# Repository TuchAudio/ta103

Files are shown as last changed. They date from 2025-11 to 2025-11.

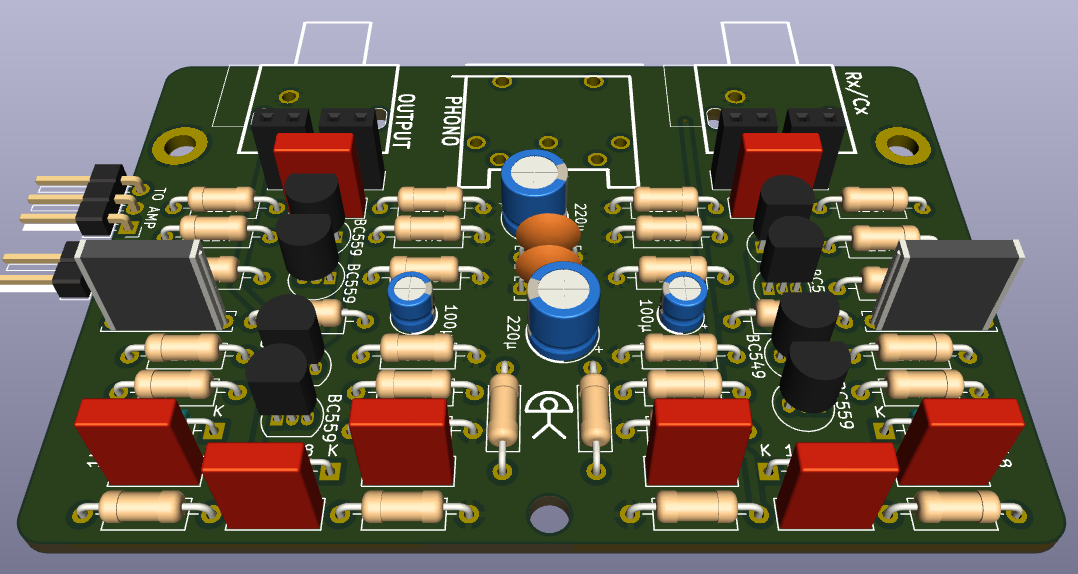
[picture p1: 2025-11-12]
pics/103-render.png

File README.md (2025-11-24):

# TuchAudio 103
Discrete, simple op-amp phono preamp

## Purpose
The most simple discrete op-amp, with **just 4 transistors** per channel -- a _3-transistor_ design was tried, but performed poorly.

## Design quirks

An op-amp this simple doesn't have too much of _open-loop gain_, thus the approximate formulae usually used are **no longer valid**. For this reason, _bass performance_ is just acceptable (but within _DIN 45.500_ specs).

DIN and RCA jacks are provided for signal input. Since the _native_ input impedance is around **110 kΩ**, space for suitable load (`Rx` and `Cx`) is provided for perfect adaptation; but for added flexibility, it is possible to use the free input for a suitable RC combo in parallel, to match the appropriate cartridge load.

Originally intended to be connected thru the [501 Input Selector board](../../../ta501), both output pins and power input are at compatible locations within each board. An aditional RCA **output** jack can be installed in order to use the circuit as a _stand-alone preamp_.

The use of an _asymmetric_ power supply (and its associated feedback _DC-blocking capacitor_) means that **it takes a few seconds** for the preamp to operate after powerup (or a noticeable supply voltage change).

### Stability

As any other amplifier with _asymmetrical power supply_, the PSRR is very poor, thus a **well filtered, stable** power supply is essential. Increasing (within reason) `R115/R215` may help a bit.

### Suggested mods

#### Standalone mode

Despite being designed around a 12 Volt power supply, this can be run from a single **9 Volt battery**, with minor changes and similar performance.

- `R115/R215`: use **220 Ω** instead of 330.
- `R103/R110/R203/R210`: use **8.2 kΩ** instead of 12K.

#### IEC1976/Neumann ammendments

The stated values are designed around these _ammendments_ to the **RIAA curve**; but since they're currently _deprecated_, you may get **improved bass response** by turning back to RIAA correction:

- `C104/C204`: do not mount (Neumann ammendment)
- `C106/C206`: use **470 nF** or more instead of 100 nF (which made a _-3 dB point at 20 Hz_ **over 108 kΩ** of the input on the _original design_ of the 501 board)

## Specs

_Measured thru a **501 input board** (tape rec. output), 12 V supply_

- **Power supply:** 9-12 V, asymmetrical, max. 6 mA
- **Input connectors:** 2x RCA plus DIN (in parallel)
- **Gain at 1 kHz:** 47x (+33.45 dB)
- **Input sensitivity:** 3.8 mV (for 180 mV output)
- **Input impedance:** 110 kΩ; adjusted by `Rx/Cx`, either internal or external.
- **Output level and impedance:** 180 mV / 3.3 KΩ
- **Overload margin:** at least +15 dB
- **Signal-to-noise ratio:** TBD
- **Frequency response:** 40 Hz - 20 kHz _(+0.25/-3 dB deviation from RIAA)_
- **Distortion:**

| Harmonic | nominal output | +15 dB overload |
| --- | --- | --- |
| 2nd | negligible | 0.5 % |
| 3rd | 0.1 % | 0.9 % |
| 4th | 0.11 % | 0.3 %  |

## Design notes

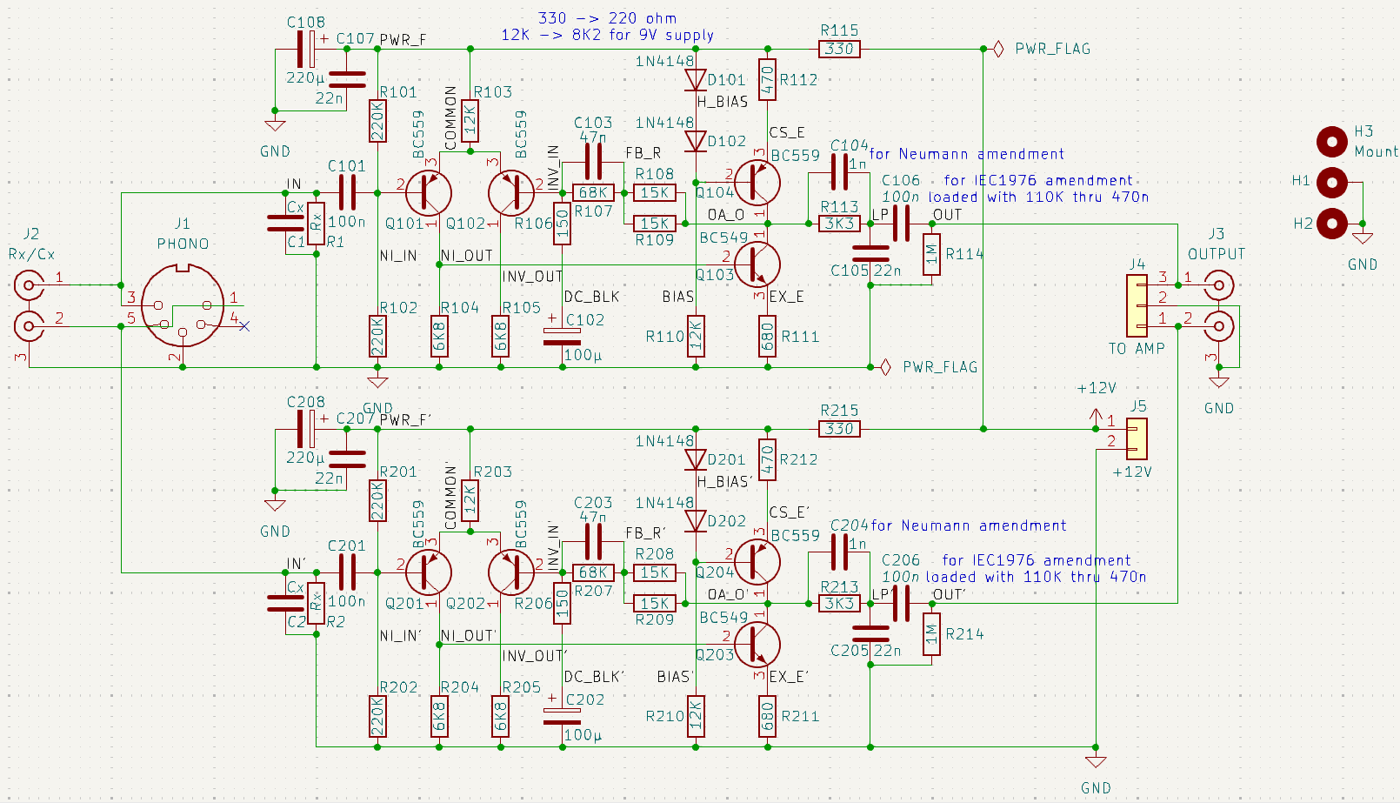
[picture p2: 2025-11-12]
pics/103-schematic.png

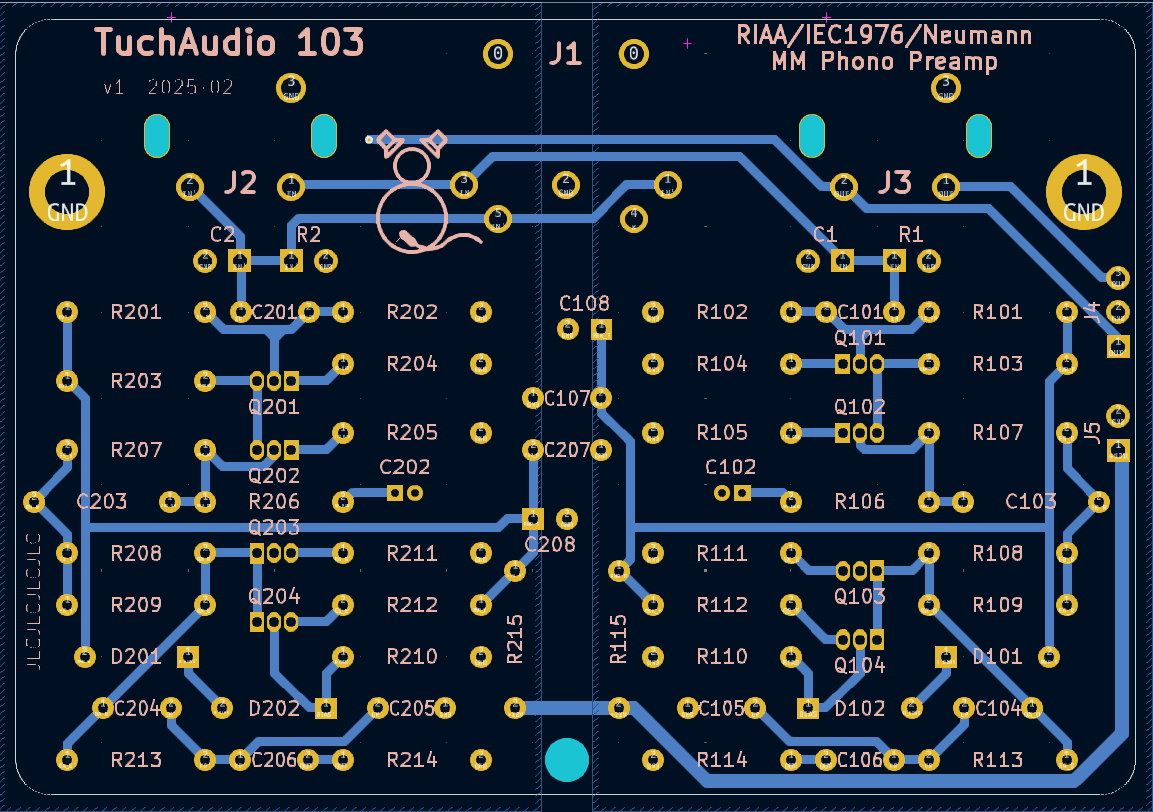
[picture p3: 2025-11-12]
pics/103-pcb-back.png

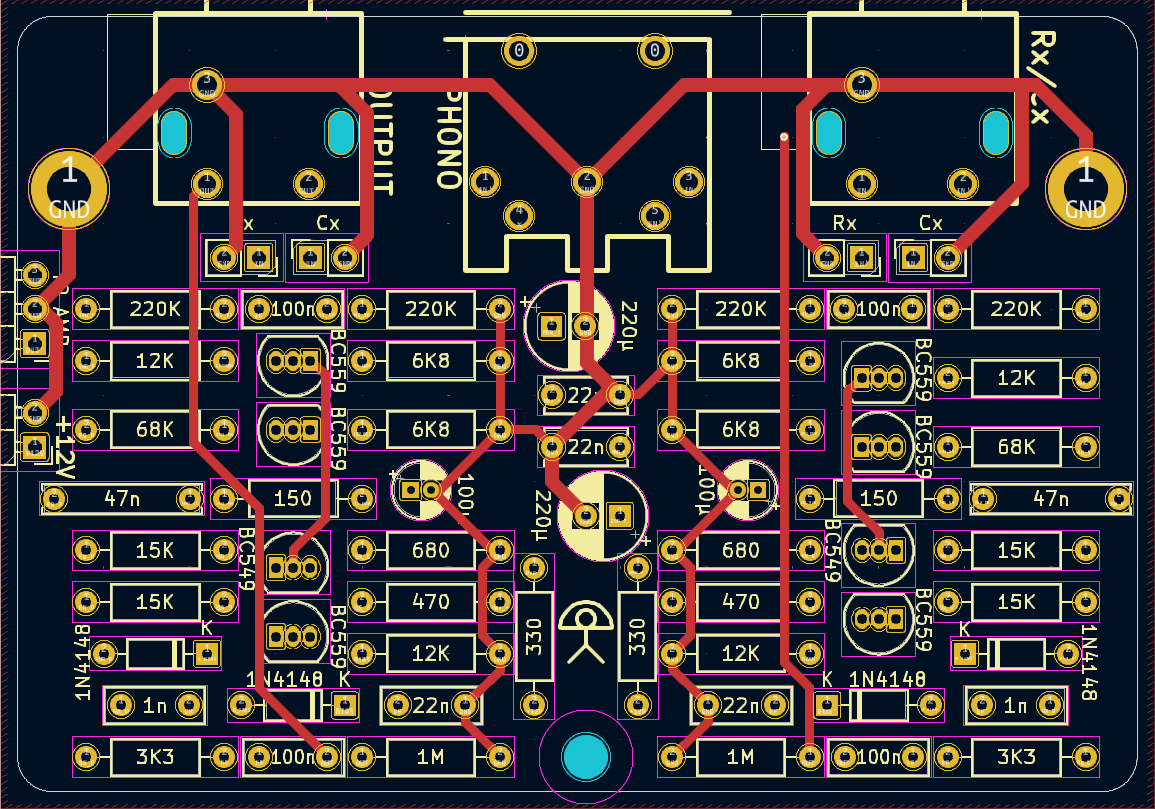
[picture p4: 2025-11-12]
pics/103-pcb-front.png

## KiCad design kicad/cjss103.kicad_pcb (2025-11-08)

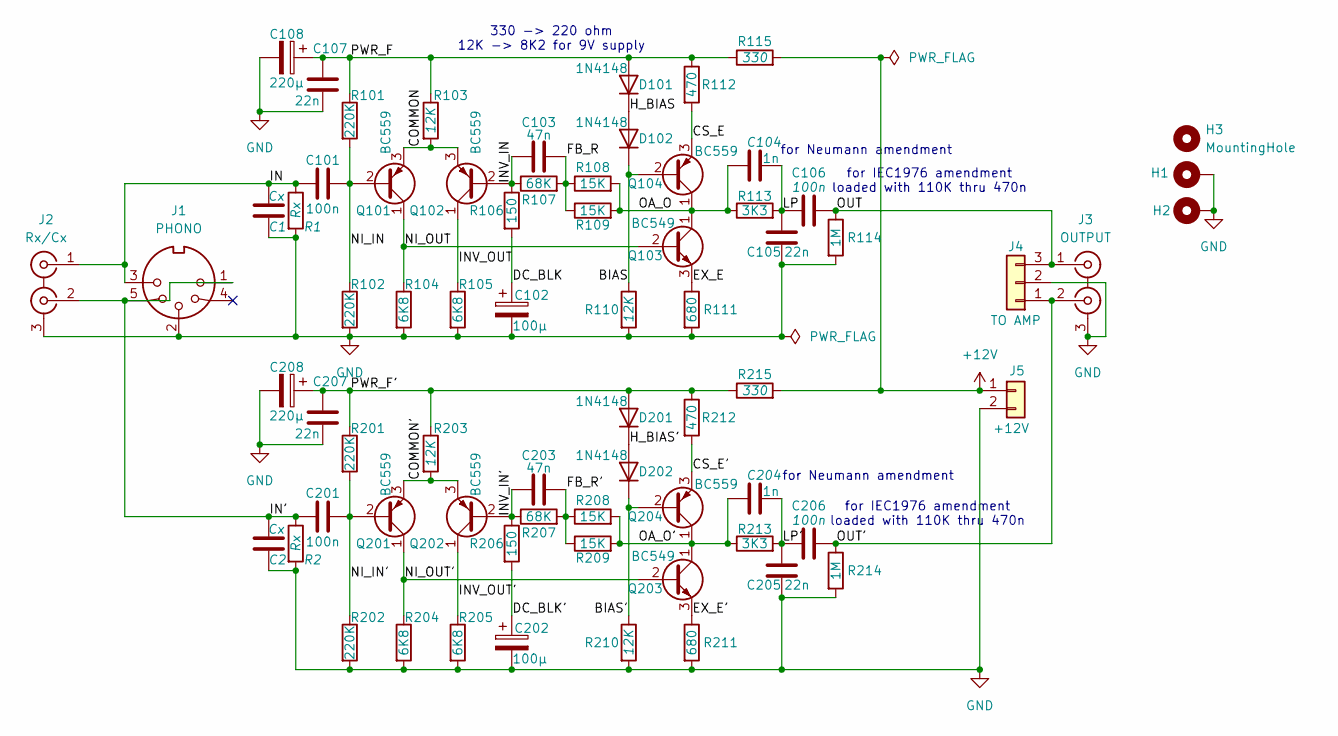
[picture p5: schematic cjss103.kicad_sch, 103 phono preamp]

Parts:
C1, C2: Cx; PinSocket_1x02_P2.54mm_Vertical
C101, C106, C201, C206: 100n; C_Rect_L7.2mm_W2.5mm_P5.00mm_FKS2_FKP2_MKS2_MKP2
C102, C202: 100µ; CP_Radial_D4.0mm_P1.50mm
C103, C203: 47n; C_Rect_L11.5mm_W2.0mm_P10.00mm_MKT
C104, C204: 1n; C_Rect_L7.2mm_W2.5mm_P5.00mm_FKS2_FKP2_MKS2_MKP2
C105, C205: 22n; C_Rect_L7.2mm_W2.5mm_P5.00mm_FKS2_FKP2_MKS2_MKP2
C107, C207: 22n; C_Disc_D6.0mm_W2.5mm_P5.00mm
C108, C208: 220µ; CP_Radial_D6.3mm_P2.50mm
D101, D102, D201, D202: 1N4148; D_DO-35_SOD27_P7.62mm_Horizontal
H1, H2: MountingHole_Pad; MountingHole_3.2mm_M3_DIN965_Pad
H3: MountingHole; MountingHole_3.2mm_M3
J1: PHONO; DIN 5-180deg
J2: Rx/Cx; 2xRCA_vertical
J3: OUTPUT; 2xRCA_vertical
J4: TO AMP; PinHeader_1x03_P2.54mm_Horizontal
J5: +12V; PinHeader_1x02_P2.54mm_Horizontal
Q101, Q102, Q104, Q201, Q202, Q204: BC559; TO-92_Inline
Q103, Q203: BC549; TO-92_Inline
R1, R2: Rx; PinSocket_1x02_P2.54mm_Vertical
R101, R102, R201, R202: 220K; R_Axial_DIN0207_L6.3mm_D2.5mm_P10.16mm_Horizontal
R103, R110, R203, R210: 12K; R_Axial_DIN0207_L6.3mm_D2.5mm_P10.16mm_Horizontal
R104, R105, R204, R205: 6K8; R_Axial_DIN0207_L6.3mm_D2.5mm_P10.16mm_Horizontal
R106, R206: 150; R_Axial_DIN0207_L6.3mm_D2.5mm_P10.16mm_Horizontal
R107, R207: 68K; R_Axial_DIN0207_L6.3mm_D2.5mm_P10.16mm_Horizontal
R108, R109, R208, R209: 15K; R_Axial_DIN0207_L6.3mm_D2.5mm_P10.16mm_Horizontal
R111, R211: 680; R_Axial_DIN0207_L6.3mm_D2.5mm_P10.16mm_Horizontal
R112, R212: 470; R_Axial_DIN0207_L6.3mm_D2.5mm_P10.16mm_Horizontal
R113, R213: 3K3; R_Axial_DIN0207_L6.3mm_D2.5mm_P10.16mm_Horizontal
R114, R214: 1M; R_Axial_DIN0207_L6.3mm_D2.5mm_P10.16mm_Horizontal
R115, R215: 330; R_Axial_DIN0207_L6.3mm_D2.5mm_P10.16mm_Horizontal

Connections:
+12V: J5.1, R115.2, R215.2
/BIAS: D102.1 (K), Q104.2 (B), R110.1
/BIAS': D202.1 (K), Q204.2 (B), R210.1
/COMMON: Q101.3 (E), Q102.3 (E), R103.2
/COMMON': Q201.3 (E), Q202.3 (E), R203.2
/CS_E: Q104.3 (E), R112.2
/CS_E': Q204.3 (E), R212.2
/DC_BLK: C102.1, R106.2
/DC_BLK': C202.1, R206.2
/EX_E: Q103.3 (E), R111.1
/EX_E': Q203.3 (E), R211.1
/FB_R: C103.2, R107.2, R108.1, R109.1
/FB_R': C203.2, R207.2, R208.1, R209.1
/H_BIAS: D101.1 (K), D102.2 (A)
/H_BIAS': D201.1 (K), D202.2 (A)
/IN: C1.1, C101.1, J1.3, J2.1 (IN1), R1.1
/IN': C2.1, C201.1, J1.1, J1.5, J2.2 (IN2), R2.1
/INV_IN: C103.1, Q102.2 (B), R106.1, R107.1
/INV_IN': C203.1, Q202.2 (B), R206.1, R207.1
/INV_OUT: Q102.1 (C), R105.1
/INV_OUT': Q202.1 (C), R205.1
/LP: C104.2, C105.2, C106.1, R113.2
/LP': C204.2, C205.2, C206.1, R213.2
/NI_IN: C101.2, Q101.2 (B), R101.2, R102.1
/NI_IN': C201.2, Q201.2 (B), R201.2, R202.1
/NI_OUT: Q101.1 (C), Q103.2 (B), R104.1
/NI_OUT': Q201.1 (C), Q203.2 (B), R204.1
/OA_O: C104.1, Q103.1 (C), Q104.1 (C), R108.2, R109.2, R113.1
/OA_O': C204.1, Q203.1 (C), Q204.1 (C), R208.2, R209.2, R213.1
/OUT: C106.2, J3.1 (IN1), J4.3, R114.1
/OUT': C206.2, J3.2 (IN2), J4.1, R214.1
/PWR_F: C107.2, C108.1, D101.2 (A), R101.1, R103.1, R112.1, R115.1
/PWR_F': C207.2, C208.1, D201.2 (A), R201.1, R203.1, R212.1, R215.1
GND: C1.2, C2.2, C102.2, C105.1, C107.1, C108.2, C202.2, C205.1, C207.1, C208.2, H1.1, H2.1, J1.2, J2.3 (EXT), J3.3 (EXT), J4.2, J5.2, R1.2, R2.2, R102.2, R104.2, R105.2, R110.2, R111.2, R114.2, R202.2, R204.2, R205.2, R210.2, R211.2, R214.2

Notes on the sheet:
for Neumann amendment
for IEC1976 amendment loaded with 110K thru 470n
330 -> 220 ohm 12K -> 8K2 for 9V supply

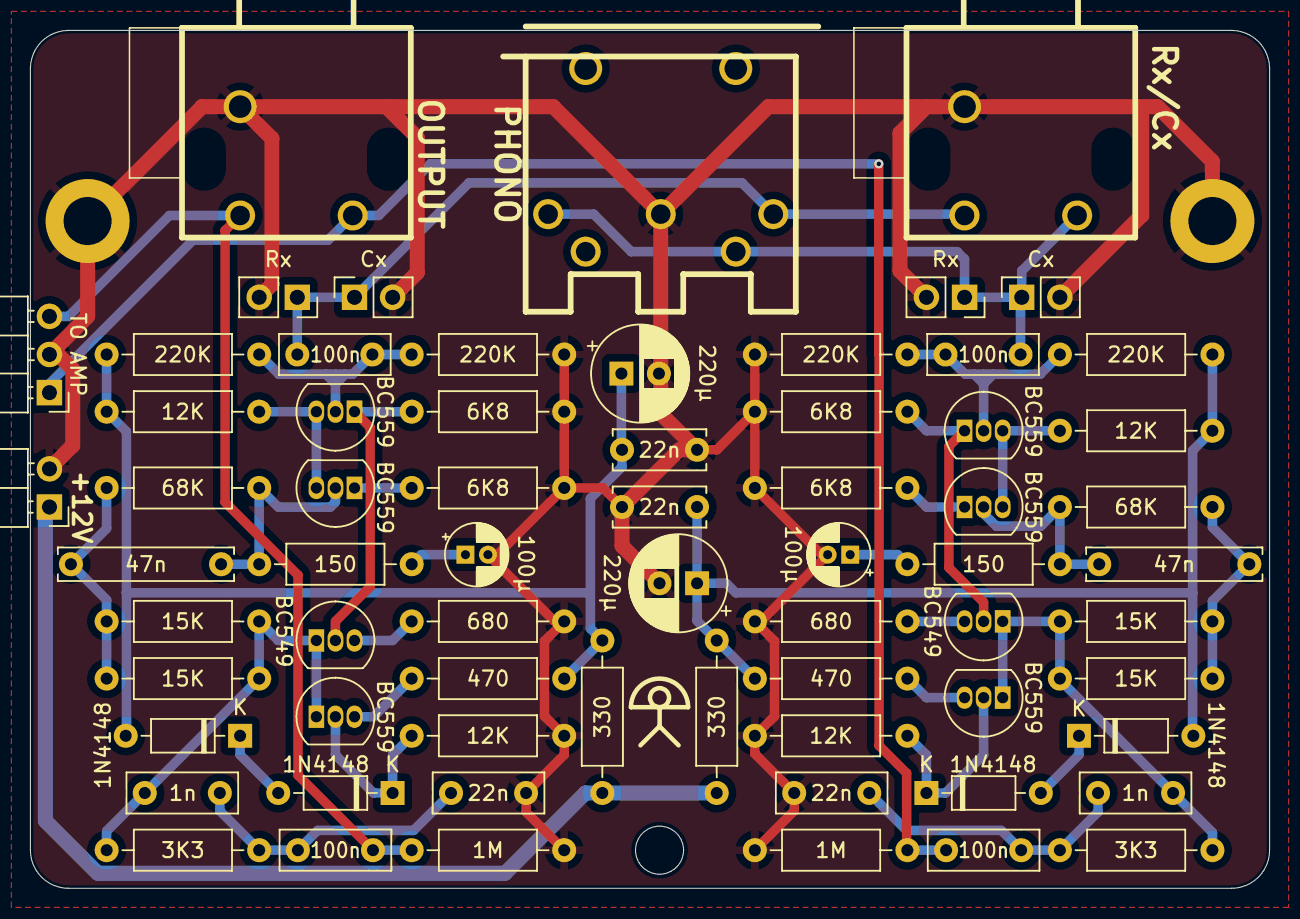
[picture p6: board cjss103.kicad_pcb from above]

Board: 2 copper layers, 82.6 x 57.2 mm, 70 parts (0 on the bottom side), 34 nets.
